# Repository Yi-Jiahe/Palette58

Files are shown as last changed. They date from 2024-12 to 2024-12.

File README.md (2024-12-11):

# Palette 58

My first (to-be) split ergonomic keyboard.

4x6 column staggered board with 5 key thumb cluster utilizing low profile switches.

The Palette 58 is meant to be an introductory keyboard, heavily inspired by the Sofle.

It includes a number row and additional outer pinky column to support a wider range of layouts to allow for experimentation.

Compared to the Sofle, it features a more aggressive pinky stagger and no additional flex key.

No LEDs because of the added complexity and cost.

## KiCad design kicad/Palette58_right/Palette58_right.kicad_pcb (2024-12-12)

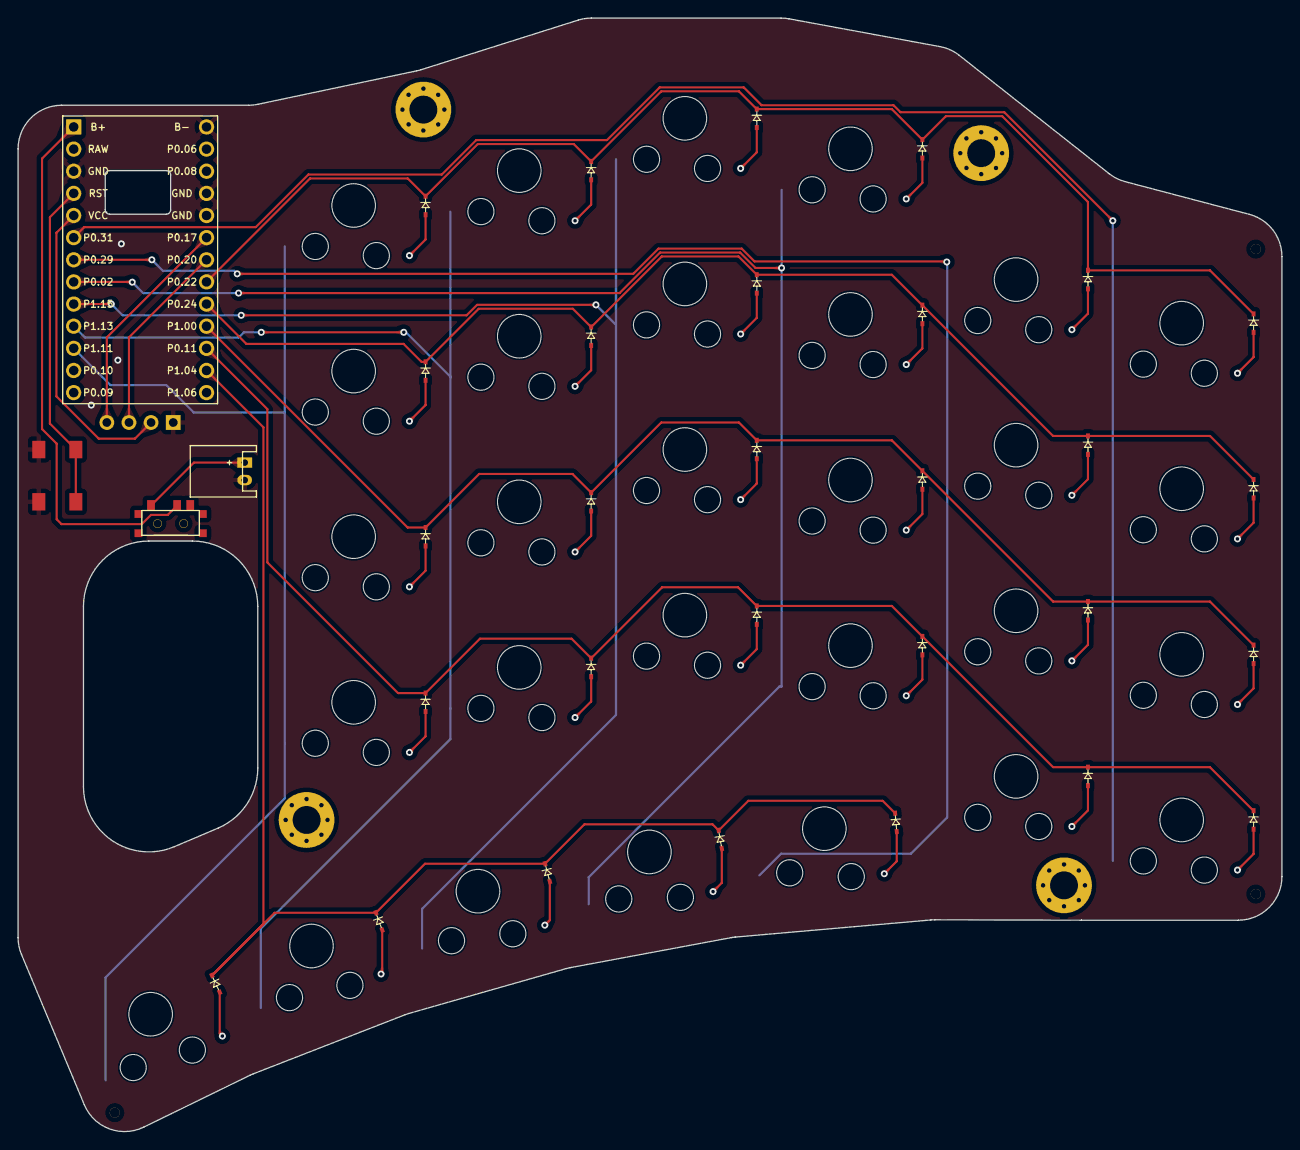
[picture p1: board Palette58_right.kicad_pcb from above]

Board: 2 copper layers, 145.0 x 127.8 mm, 66 parts (0 on the bottom side), 47 nets.

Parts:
D1, D2, D3, D4, D5, D6, D7, D8, D9, D10, D11, D12, D13, D14, D15, D16, D17, D18, D19, D20, D21, D22, D23, D24, D25, D26, D27, D28, D29: 1N4148; ComboDiode
JST1: JST_PH_S2B-PH-K_02x2.00mm_Angled
MCU1: nice!nanov2
OLED1: OLED; OLED_headers
S1, S2, S3, S4, S5, S6, S7, S8, S9, S10, S11, S12, S13, S14, S15, S16, S17, S18, S19, S20, S21, S22, S23, S24, S25, S26, S27, S28, S29: Gaeteron_low_profile
SW1: MSK12C02-HB; SPDT_C128955
SW2: TS-1187A-B-A-B; PushSwitch
_34, _35, _36: ToolingHole

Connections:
B+: MCU1.1, SW1.2
GND: JST1.2, MCU1.3, MCU1.14, MCU1.17, MCU1.18, OLED1.1, SW2.3, SW2.4
JST+: JST1.1, SW1.1
RST: MCU1.4, SW2.1, SW2.2
SCL: MCU1.20, OLED1.3
SDA: MCU1.19, OLED1.4
VCC: MCU1.5, OLED1.2
col_1: MCU1.6, S1.1, S2.1, S3.1, S4.1
col_2: MCU1.7, S5.1, S6.1, S7.1, S8.1, S25.1
col_3: MCU1.8, S9.1, S10.1, S11.1, S12.1, S26.1
col_4: MCU1.9, S13.1, S14.1, S15.1, S16.1, S27.1
col_5: MCU1.10, S17.1, S18.1, S19.1, S20.1, S28.1
col_6: MCU1.11, S21.1, S22.1, S23.1, S24.1, S29.1
mirror_home_cluster: D28.2, S28.2
mirror_index_bottom: D17.2, S17.2
mirror_index_home: D18.2, S18.2
mirror_index_num: D20.2, S20.2
mirror_index_top: D19.2, S19.2
mirror_inner_bottom: D21.2, S21.2
mirror_inner_cluster: D29.2, S29.2
mirror_inner_home: D22.2, S22.2
mirror_inner_num: D24.2, S24.2
mirror_inner_top: D23.2, S23.2
mirror_middle_bottom: D13.2, S13.2
mirror_middle_home: D14.2, S14.2
mirror_middle_num: D16.2, S16.2
mirror_middle_top: D15.2, S15.2
mirror_outer-2_cluster: D26.2, S26.2
mirror_outer-3_cluster: D25.2, S25.2
mirror_outer_bottom: D1.2, S1.2
mirror_outer_cluster: D27.2, S27.2
mirror_outer_home: D2.2, S2.2
mirror_outer_num: D4.2, S4.2
mirror_outer_top: D3.2, S3.2
mirror_pinky_bottom: D5.2, S5.2
mirror_pinky_home: D6.2, S6.2
mirror_pinky_num: D8.2, S8.2
mirror_pinky_top: D7.2, S7.2
mirror_ring_bottom: D9.2, S9.2
mirror_ring_home: D10.2, S10.2
mirror_ring_num: D12.2, S12.2
mirror_ring_top: D11.2, S11.2
row_1: D4.1, D8.1, D12.1, D16.1, D20.1, D24.1, MCU1.21
row_2: D3.1, D7.1, D11.1, D15.1, D19.1, D23.1, MCU1.22
row_3: D2.1, D6.1, D10.1, D14.1, D18.1, D22.1, MCU1.23
row_4: D1.1, D5.1, D9.1, D13.1, D17.1, D21.1, MCU1.24
row_5: D25.1, D26.1, D27.1, D28.1, D29.1, MCU1.25

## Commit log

2024-11-06 feature: define gateron low profile footprint
2024-11-06 chore: move diode to right
2024-11-06 feature: Add nice!nano_v2 footprint
2024-11-08 feature: add power circuitry
2024-11-09 chore: adjust power component placements
2024-11-09 feature: add decoupling capacitors
2024-11-09 feature: Add values to diodes
2024-11-09 Add reset button
2024-11-09 Init kicad project
    [Palette58.kicad_pcb, Palette58.kicad_sch]
2024-11-10 change smd diode footprint to 323
    [Palette58.kicad_pcb, Palette58.kicad_sch]
2024-11-10 straighten mirrored edge
    [Palette58.kicad_pcb]
2024-11-10 Reflect board
    [Palette58.kicad_pcb, Palette58.kicad_sch]
2024-11-10 Route simple routes
    [Palette58.kicad_pcb]
2024-11-10 Route left half
    [Palette58.kicad_pcb, Palette58.kicad_sch]
2024-11-10 Finish Routing
    [Palette58.kicad_pcb, Palette58.kicad_sch]
2024-11-12 Split pcb into two projects
    [Palette58.kicad_pcb, Palette58.kicad_sch, Palette58_left.kicad_pcb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]
2024-11-12 Add mounting holes
    [Palette58_left.kicad_pcb, Palette58_right.kicad_pcb]
2024-11-12 Add tooling holes
    [Palette58_left.kicad_pcb, Palette58_right.kicad_pcb]
2024-11-12 fix: add vias back to left half hotswap pads
    [Palette58_left.kicad_pcb]
2024-11-12 fix: fix capacitor and via placement
    [Palette58_left.kicad_pcb, Palette58_right.kicad_pcb]
2024-11-12 Send left half for production
    [Palette58_left.kicad_pcb]
2024-11-30 fix: Fix via footprint
2024-12-11 Simplify left half
    [Palette58_left.kicad_pcb, Palette58_left.kicad_sch]
2024-12-11 Update right half
    [Palette58_right.kicad_pcb, Palette58_right.kicad_sch]
2024-12-12 Send right side for production
    [Palette58_right.kicad_pcb]
